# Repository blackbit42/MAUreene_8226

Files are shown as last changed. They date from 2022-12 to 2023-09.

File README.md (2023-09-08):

> [!WARNING]
> The current revision of the board is not functional. Build only if you want to work on fixing it.

# Token Ring MAU 'MAUreen'

MAUreene 8226 is a Token Ring (IEEE 802.5) Media Access Unit (MAU) that is inspired by the IBM 8226. For the most part, it is a reproduction of the IBM 8226, reduced to 2 'lobes', which is Token Ring lingo for what is known as a port in the context of other network technologies.

## Motivation

Token Ring is an interesting LAN technology. NICs are all over common auction sites and can be had cheaply, though MAUs are hard to come by. The intent of this project is to enable inclined people to play with Token Ring more easily.

## Clarification regarding 'crossover' cables

In an ethernet network you can nowadays connect two arbitrary devices with each other back to back without thinking about it, due to to the power of Auto MDI-X. Earlier you could use so-called 'crossover' cables. Unfortunately Token Ring doesn't support such a mode of interconnection, as a NIC goes through a mildly elaborated attachment process with a MAU. A mode where two hosts talk directly to each other doesn't exist, see [this](https://www.tavi.co.uk/ps2pages/ohland/8228.html#DirectCable).

## BOM analysis and mapping

| Original 8226 | Lobe 1 | Lobe 2  | Package | Type | Measured value[^1] | Marking | Remarks |
| --- | --- | --- | --- | --- | --- | --- | --- |
| R2 | R1 | R21 | 0805 | | 4.8k | 4871 | |
| R10 | R2 | R22 | 0603 | | -None- | -None- | Opto-coupler biasing, not populated |
| R34 | R3 | R23 | 0603 | | 0.3 | 000 | RJ45 termination |
| R35 | R4 | R24 | 0603 | | 0.3 | 000 | RJ45 termination |
| R44 | R5 | R25 | 0603 | | 100 | 101 | |
| R52 | R6 | R26 | 0603 | | 100 | 101 | |
| R60 | R7 | R27 | 0603 | | | 104 | |
| R68 | R8 | R28 | 0603 | | 10k | 103 | |
| R76 | R9 | R29 | 0603 | | 2k | 202 | |
| R84 | R10 | R30 | 0805 | | 3.7k | 3741 | |
| R92 | R11 | R31 | 0603 | | 4.7k | 472 | LED series resistor |
| R96 | R12 | R32 | 0603 | | 0.3 | 000 | RJ45 termination |
| R97 | R13 | R33 | 0603 | | 0.3 | 000 | RJ45 termination |
| C4 | C1 | C21 | 1812 | Ceramic | 330n | -None- | |
| C12 | C2 | C22 | 1812 | Ceramic | 330n | -None- | |
| C20 | C3 | C23 | EIA 7343-31  | Tantalum | 22u | 22-20 LD (2) | |
| C34 | C4 | C24 | 0805 | Ceramic | 120n | -None- | |
| C41 | C5 | C25 | 0805 | Ceramic | 120n | -None- | |
| Q13 | Q1 | Q21 | SOT23 | BJT NPN | | 1P | |
| Q14 | Q2 | Q22 | SOT23 | BJT NPN | | 1P | |
| CR7 | D1 | D21 | SOT23 | | 0.6 | A66 (?) | Flyback diode for coil in K2 |
| K2[^2] | K1 | K21 | Non-standard | 4PDT | | P&B T84S17D214-12 | |
| T2 | T1 | T21 | Non-standard | Special Token Ring | | Valor PT4043 | |
| DS2 | -None- | -None-  | Non-standard | | | -None- | LEDs of J1A and J1B are used |
| L2 | -None- | -None-  | -None- | -None- | | -None- | Unpopulated |
| U2 | U1 | U21 | DIP-6 | Opto-Coupler | | QTC H11A1 | | 
| -None- | J1A | J1B | Non-standard | RJ45 jack | | | |

## Power supply BOM

| Part designator | Value  | Description |
| --- | --- | --- |
| J200 | | Barrel jack |
| J201 | | 2x2 jumper 12V |
| J202 | | 2x2 jumper 5V  |
| U200 | | 5V linear reg. |
| C200 | 0.33uF | |
| C201 | 0.1uF  | |
| C202 | 0.1uF  | |
| R200 | 495Ohm | 12V rail ind.  |
| R201 | 145Ohm | 5V rail ind. |

[^1]: Capacitors have been desoldered for measurement with HP 4262A LCR meter.
[^2]: The polarity of the coil supply is reversed, both in the original and this design. Irrelevant, as the relay coils do not have series diodes.

## Diode direction
CR7 is in a 3-pin SOT23 package, containing only a single diode. It is connected in parallel with a relay coil, indicating reverse EMF protection for adjacent devices in the circuit.
Unfortunately somebody got the direction wrong, hence there is significant reverse EMF with spikes of around 200V. 
Remarkably, neither the diode itself dies from excessive forward current when the relay is on, nor the switching transistor from the voltage spikes when the relay is being switched off.
In the design of this contraption, a diode with normal flyback operation has been foreseen.

## Pictures

Photo:

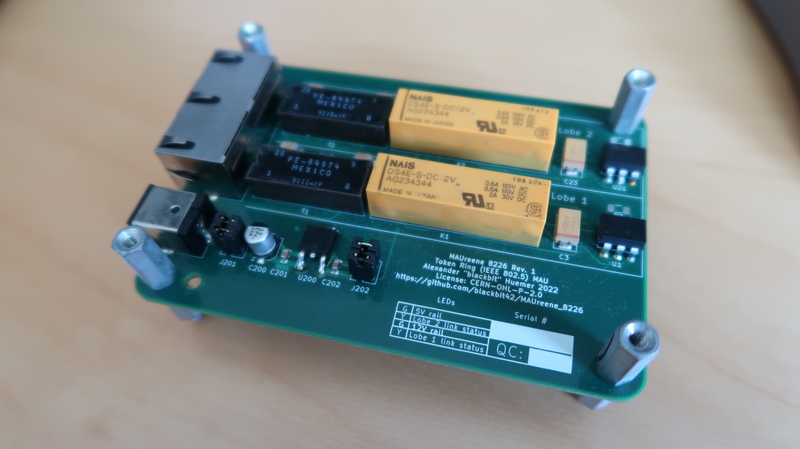
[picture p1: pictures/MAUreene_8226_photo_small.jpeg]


Kicad:

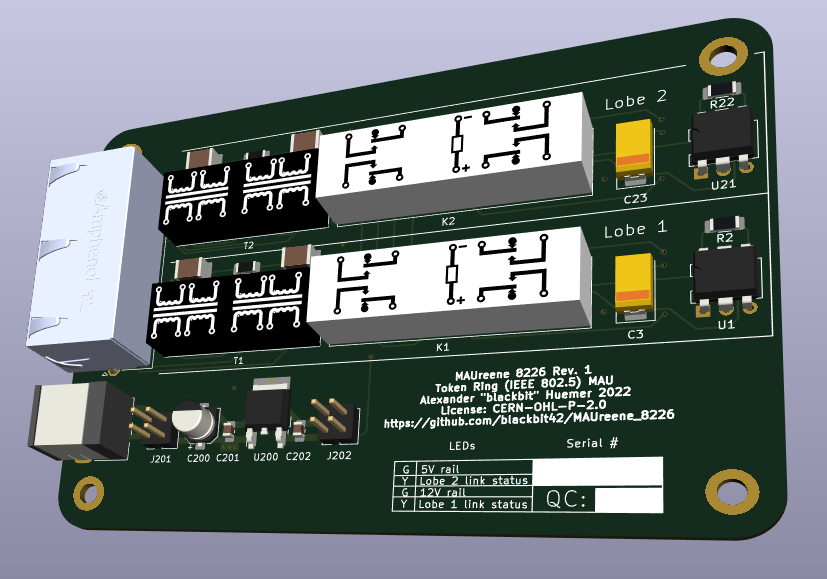
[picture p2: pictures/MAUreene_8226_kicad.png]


FreeCAD:

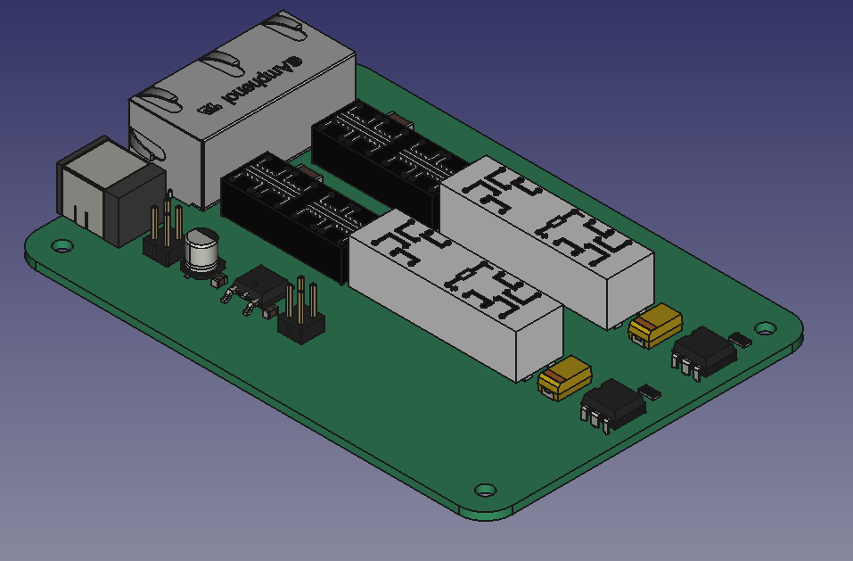
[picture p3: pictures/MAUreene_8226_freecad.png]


X-ray of original PCB, courtesy of [@Manawyrm](https://github.com/Manawyrm):

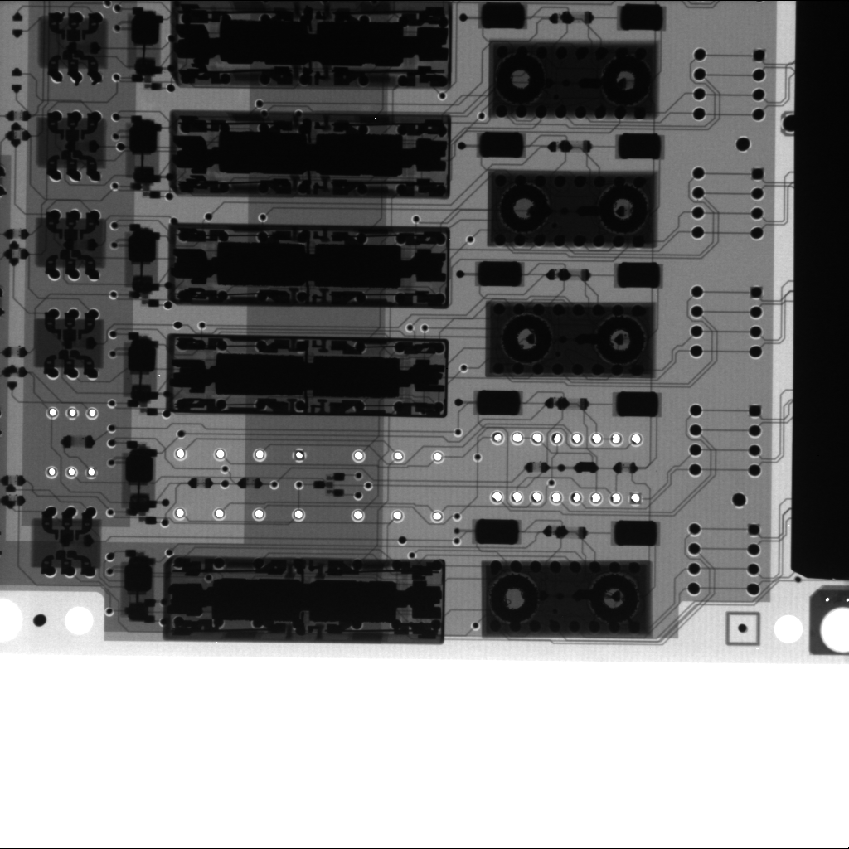
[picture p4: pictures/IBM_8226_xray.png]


## Links

<https://www.ieee802.org/5/www8025org/>

<https://ardent-tool.com/network/Understanding_Token_Ring.html>

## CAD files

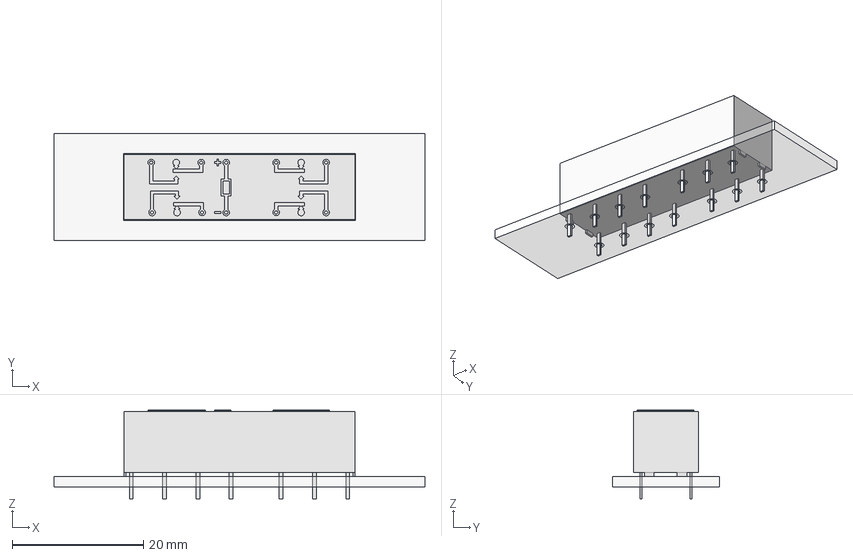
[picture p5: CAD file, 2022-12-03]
Freecad_models/4PDT_Relay.FCStd
56.6 x 16.3 x 13.5 mm
FrontSilk
TopPads
BotPads
PTHs
Pcb
4PDT_Relay

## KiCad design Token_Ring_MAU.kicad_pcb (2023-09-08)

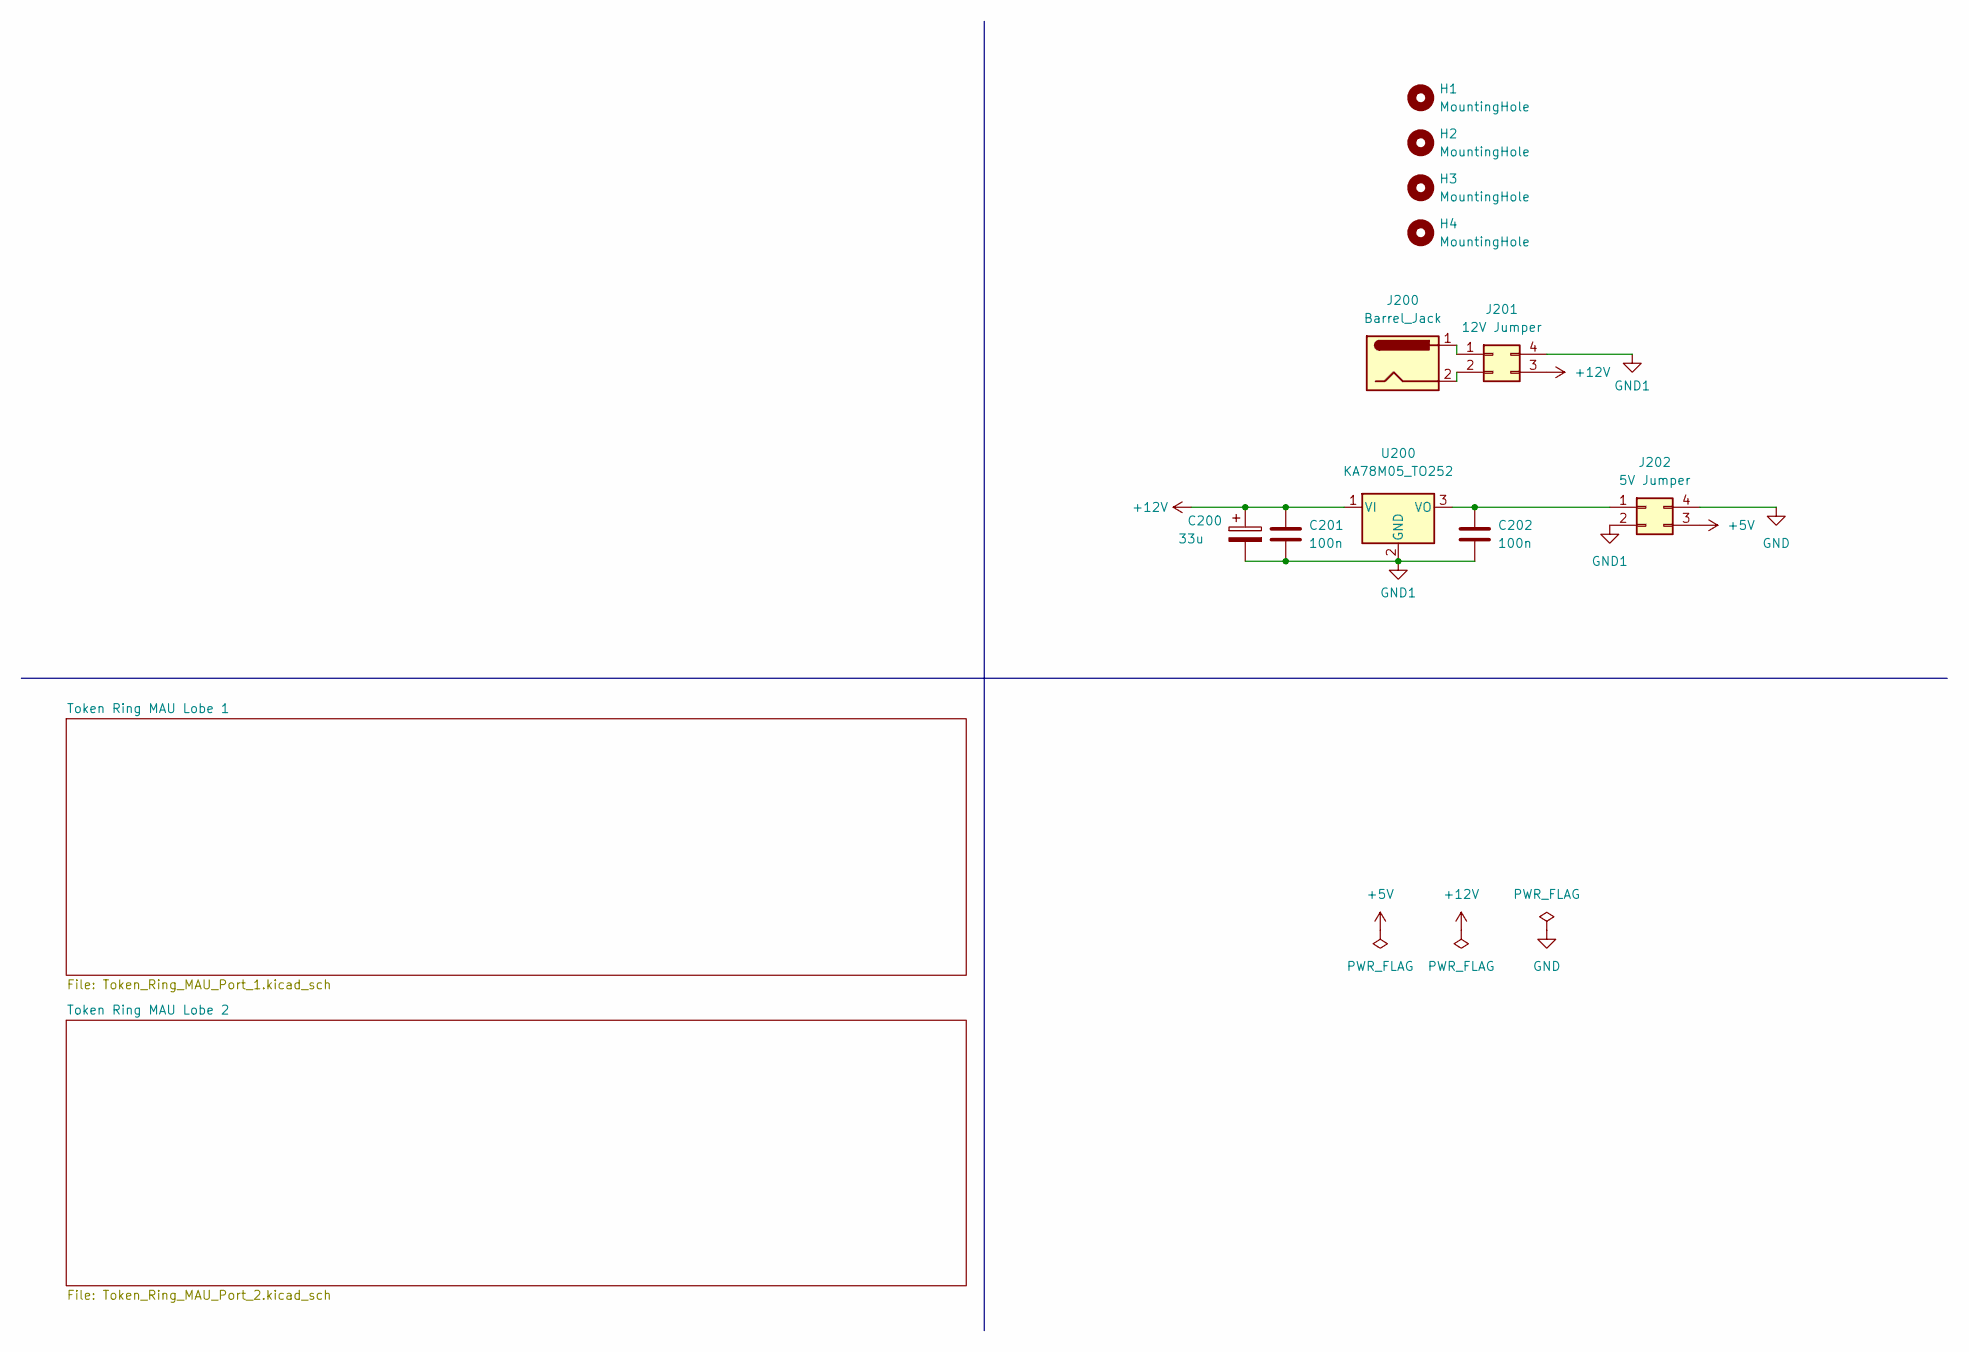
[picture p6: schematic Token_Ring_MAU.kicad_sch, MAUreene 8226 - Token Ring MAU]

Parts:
C200: 33u; CP_Elec_5x5.8; JLCPCB part number C128455
C201, C202: 100n; C_0805_2012Metric_Pad1.18x1.45mm_HandSolder; JLCPCB part number C85866
H1, H2, H3, H4: MountingHole; MountingHole_3.2mm_M3_DIN965_Pad; JLCPCB part number DNP
J200: Barrel_Jack; BarrelJack_CUI_PJ-063AH_Horizontal; JLCPCB part number DNP
J201: 12V Jumper; PinHeader_2x02_P2.54mm_Vertical; JLCPCB part number DNP
J202: 5V Jumper; PinHeader_2x02_P2.54mm_Vertical; JLCPCB part number DNP
U200: KA78M05_TO252; TO-252-2; JLCPCB part number DNP

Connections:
+5V: J202.3; also elsewhere on the board
+12V: C200.1, C201.1, J201.3, U200.1 (VI); also elsewhere on the board
GND: J202.4; also elsewhere on the board
GND1: C200.2, C201.2, C202.2, J201.4, J202.2, U200.2 (GND)
unnamed: C202.1, J202.1, U200.3 (VO)
unnamed: J200.1, J201.1
unnamed: J200.2, J201.2

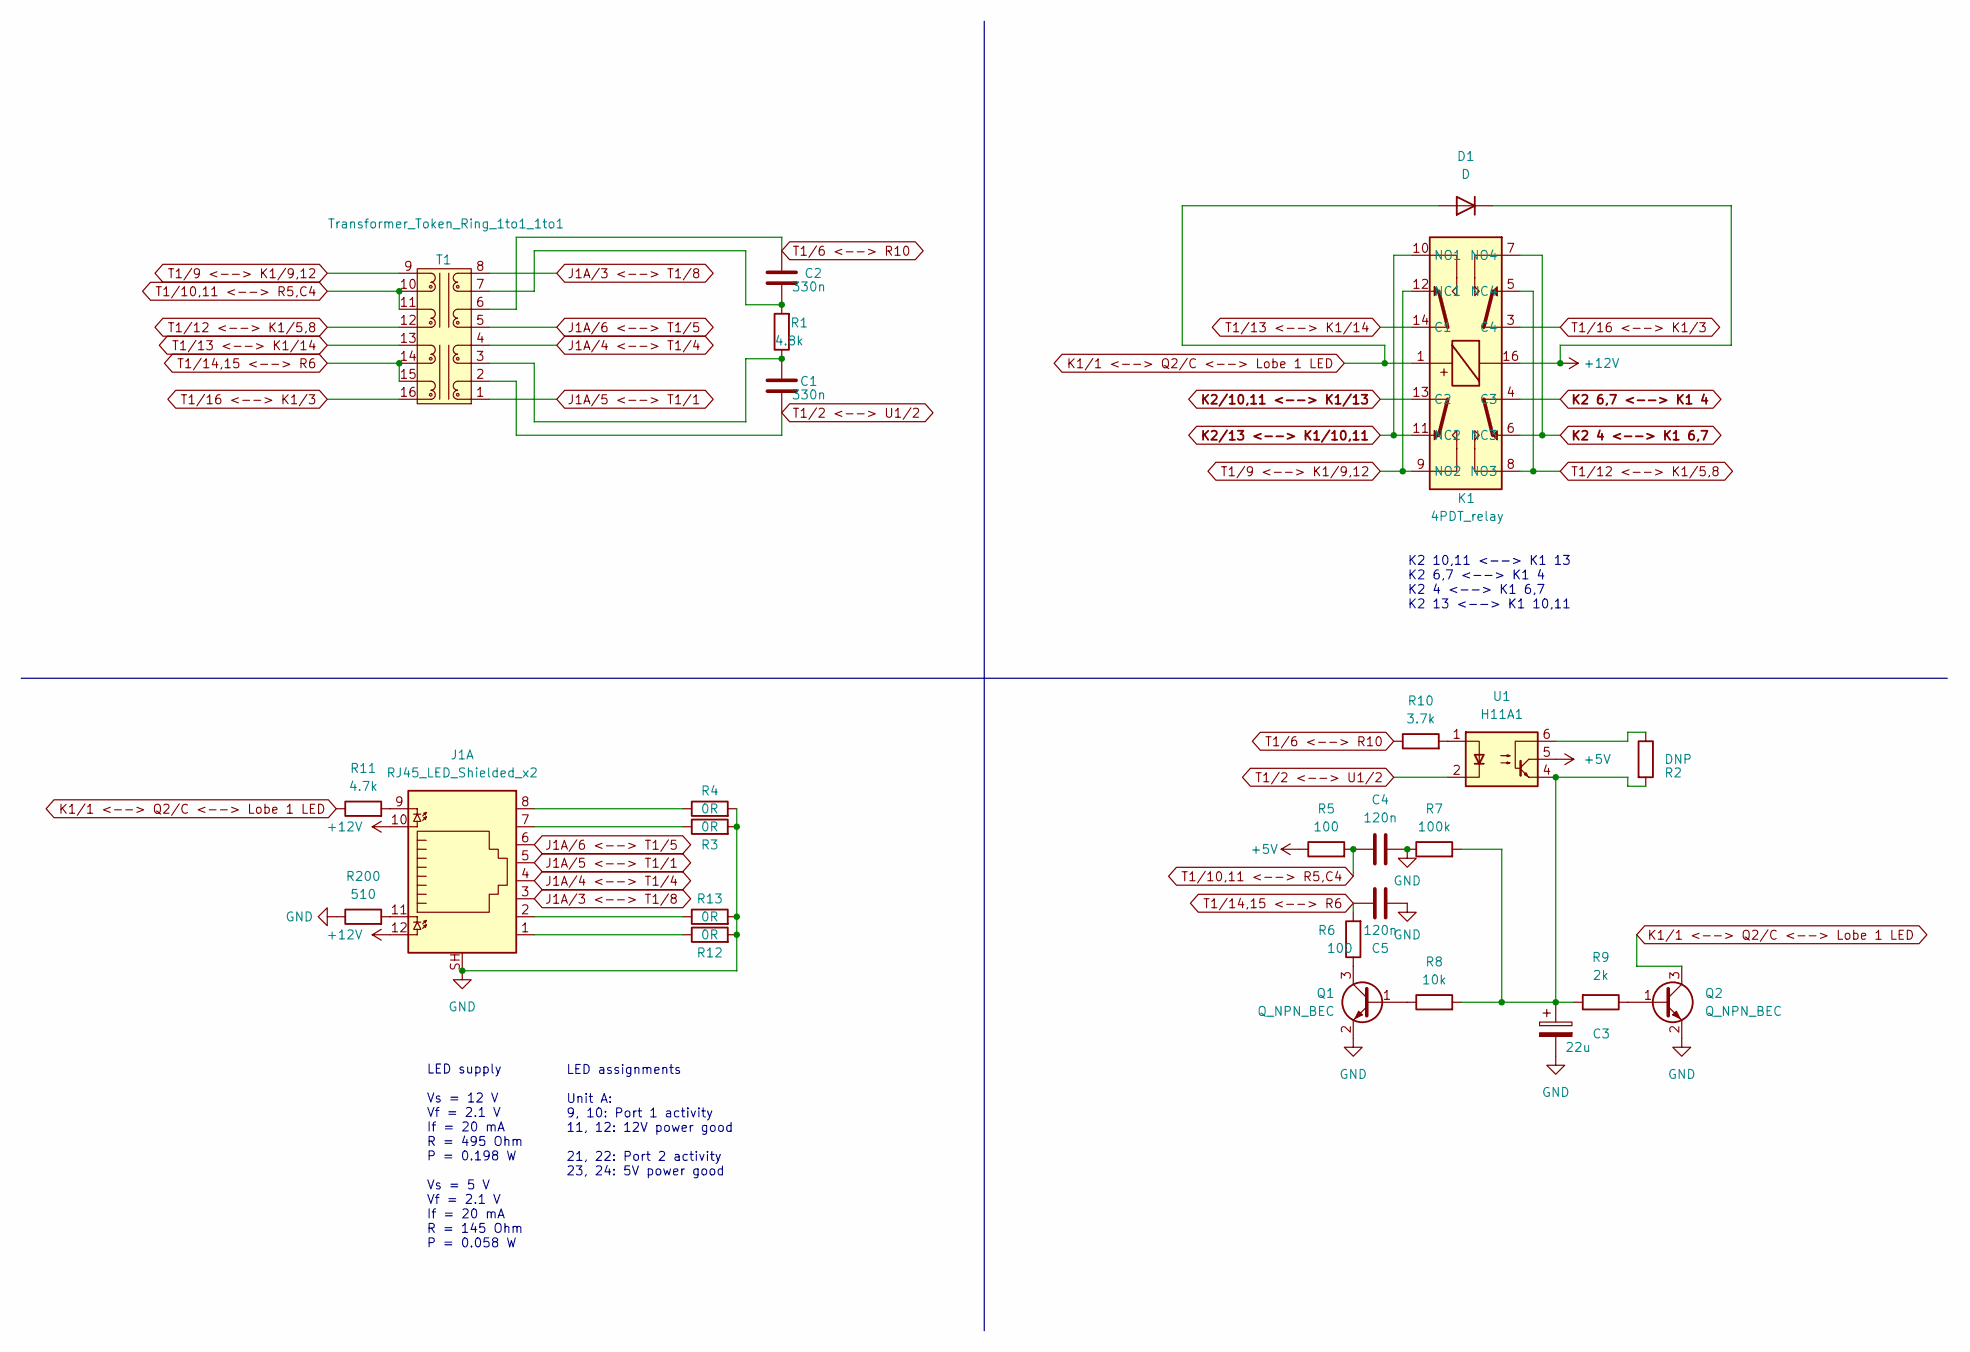
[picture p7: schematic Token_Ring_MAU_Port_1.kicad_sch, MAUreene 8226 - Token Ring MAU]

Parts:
C1, C2: 330n; C_1812_4532Metric_Pad1.57x3.40mm_HandSolder; JLCPCB part number C106167
C3: 22u; CP_EIA-7343-31_Kemet-D_Pad2.25x2.55mm_HandSolder; JLCPCB part number C7225
C4, C5: 120n; C_0603_1608Metric_Pad1.08x0.95mm_HandSolder; JLCPCB part number C282672
D1: D; D_SOD-123F; JLCPCB part number C108803
J1: RJ45_LED_Shielded_x2; RJ45_Amphenol_RJHSE538X-02; JLCPCB part number DNP
K1: 4PDT_relay; 4PDT_Relay; JLCPCB part number DNP
Q1, Q2: Q_NPN_BEC; SOT-23; JLCPCB part number C141788
R1: 4.8k; R_1206_3216Metric_Pad1.30x1.75mm_HandSolder; JLCPCB part number C323071
R2: DNP; R_1206_3216Metric_Pad1.30x1.75mm_HandSolder; JLCPCB part number DNP
R3, R4, R12, R13: 0R; R_0603_1608Metric_Pad0.98x0.95mm_HandSolder; JLCPCB part number C21189
R5, R6: 100; R_0603_1608Metric_Pad0.98x0.95mm_HandSolder; JLCPCB part number C445624
R7: 100k; R_0603_1608Metric_Pad0.98x0.95mm_HandSolder; JLCPCB part number C150003
R8: 10k; R_0603_1608Metric_Pad0.98x0.95mm_HandSolder; JLCPCB part number C100708
R9: 2k; R_0603_1608Metric_Pad0.98x0.95mm_HandSolder; JLCPCB part number C217936
R10: 3.7k; R_0805_2012Metric_Pad1.20x1.40mm_HandSolder; JLCPCB part number C403190
R11: 4.7k; R_0603_1608Metric_Pad0.98x0.95mm_HandSolder; JLCPCB part number C105428
R200: 510; R_0603_1608Metric_Pad0.98x0.95mm_HandSolder; JLCPCB part number C23193
T1: Transformer_Token_Ring_1to1_1to1; Pulse PE-64974; JLCPCB part number DNP
U1: H11A1; DIP-6_W7.62mm; JLCPCB part number DNP

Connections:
+5V: R5.1, U1.5; also elsewhere on the board
+12V: D1.1 (K), J1.10, J1.12, K1.16; also elsewhere on the board
GND: C3.2, C4.2, C5.2, J1.SH, Q1.2 (E), Q2.2 (E), R3.2, R4.2, R7.1, R12.2, R13.2, R200.1; also elsewhere on the board
J1A/3 <--> T1/8: J1.3, T1.8
J1A/4 <--> T1/4: J1.4, T1.4
J1A/5 <--> T1/1: J1.5, T1.1
J1A/6 <--> T1/5: J1.6, T1.5
K1/1 <--> Q2/C <--> Lobe 1 LED: D1.2 (A), K1.1, Q2.3 (C), R11.1
K2 4 <--> K1 6,7: K1.6 (NC3), K1.7 (NO4); also elsewhere on the board
K2 6,7 <--> K1 4: K1.4 (C3); also elsewhere on the board
K2/10,11 <--> K1/13: K1.13 (C2); also elsewhere on the board
K2/13 <--> K1/10,11: K1.10 (NO1), K1.11 (NC2); also elsewhere on the board
unnamed: C1.1, R1.1, T1.3
unnamed: C2.2, R1.2, T1.7
unnamed: C3.1, R2.2, R7.2, R8.2, R9.2, U1.4
unnamed: J1.1, R12.1
unnamed: J1.2, R13.1
unnamed: J1.7, R3.1
unnamed: J1.8, R4.1
unnamed: J1.9, R11.2
unnamed: J1.11, R200.2
unnamed: Q1.1 (B), R8.1
unnamed: Q1.3 (C), R6.1
unnamed: Q2.1 (B), R9.1
unnamed: R2.1, U1.6
unnamed: R10.2, U1.1
T1/2 <--> U1/2: C1.2, T1.2, U1.2
T1/6 <--> R10: C2.1, R10.1, T1.6
T1/9 <--> K1/9,12: K1.9 (NO2), K1.12 (NC1), T1.9
T1/10,11 <--> R5,C4: C4.1, R5.2, T1.10, T1.11
T1/12 <--> K1/5,8: K1.5 (NC4), K1.8 (NO3), T1.12
T1/13 <--> K1/14: K1.14 (C1), T1.13
T1/14,15 <--> R6: C5.1, R6.2, T1.14, T1.15
T1/16 <--> K1/3: K1.3 (C4), T1.16

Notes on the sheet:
K2 10,11 <--> K1 13 K2 6,7 <--> K1 4 K2 4 <--> K1 6,7 K2 13 <--> K1 10,11
LED assignments Unit A: 9, 10: Port 1 activity 11, 12: 12V power good 21, 22: Port 2 activity 23, 24: 5V power good
LED supply Vs = 12 V Vf = 2.1 V If = 20 mA R = 495 Ohm P = 0.198 W Vs = 5 V Vf = 2.1 V If = 20 mA R = 145 Ohm P = 0.058 W

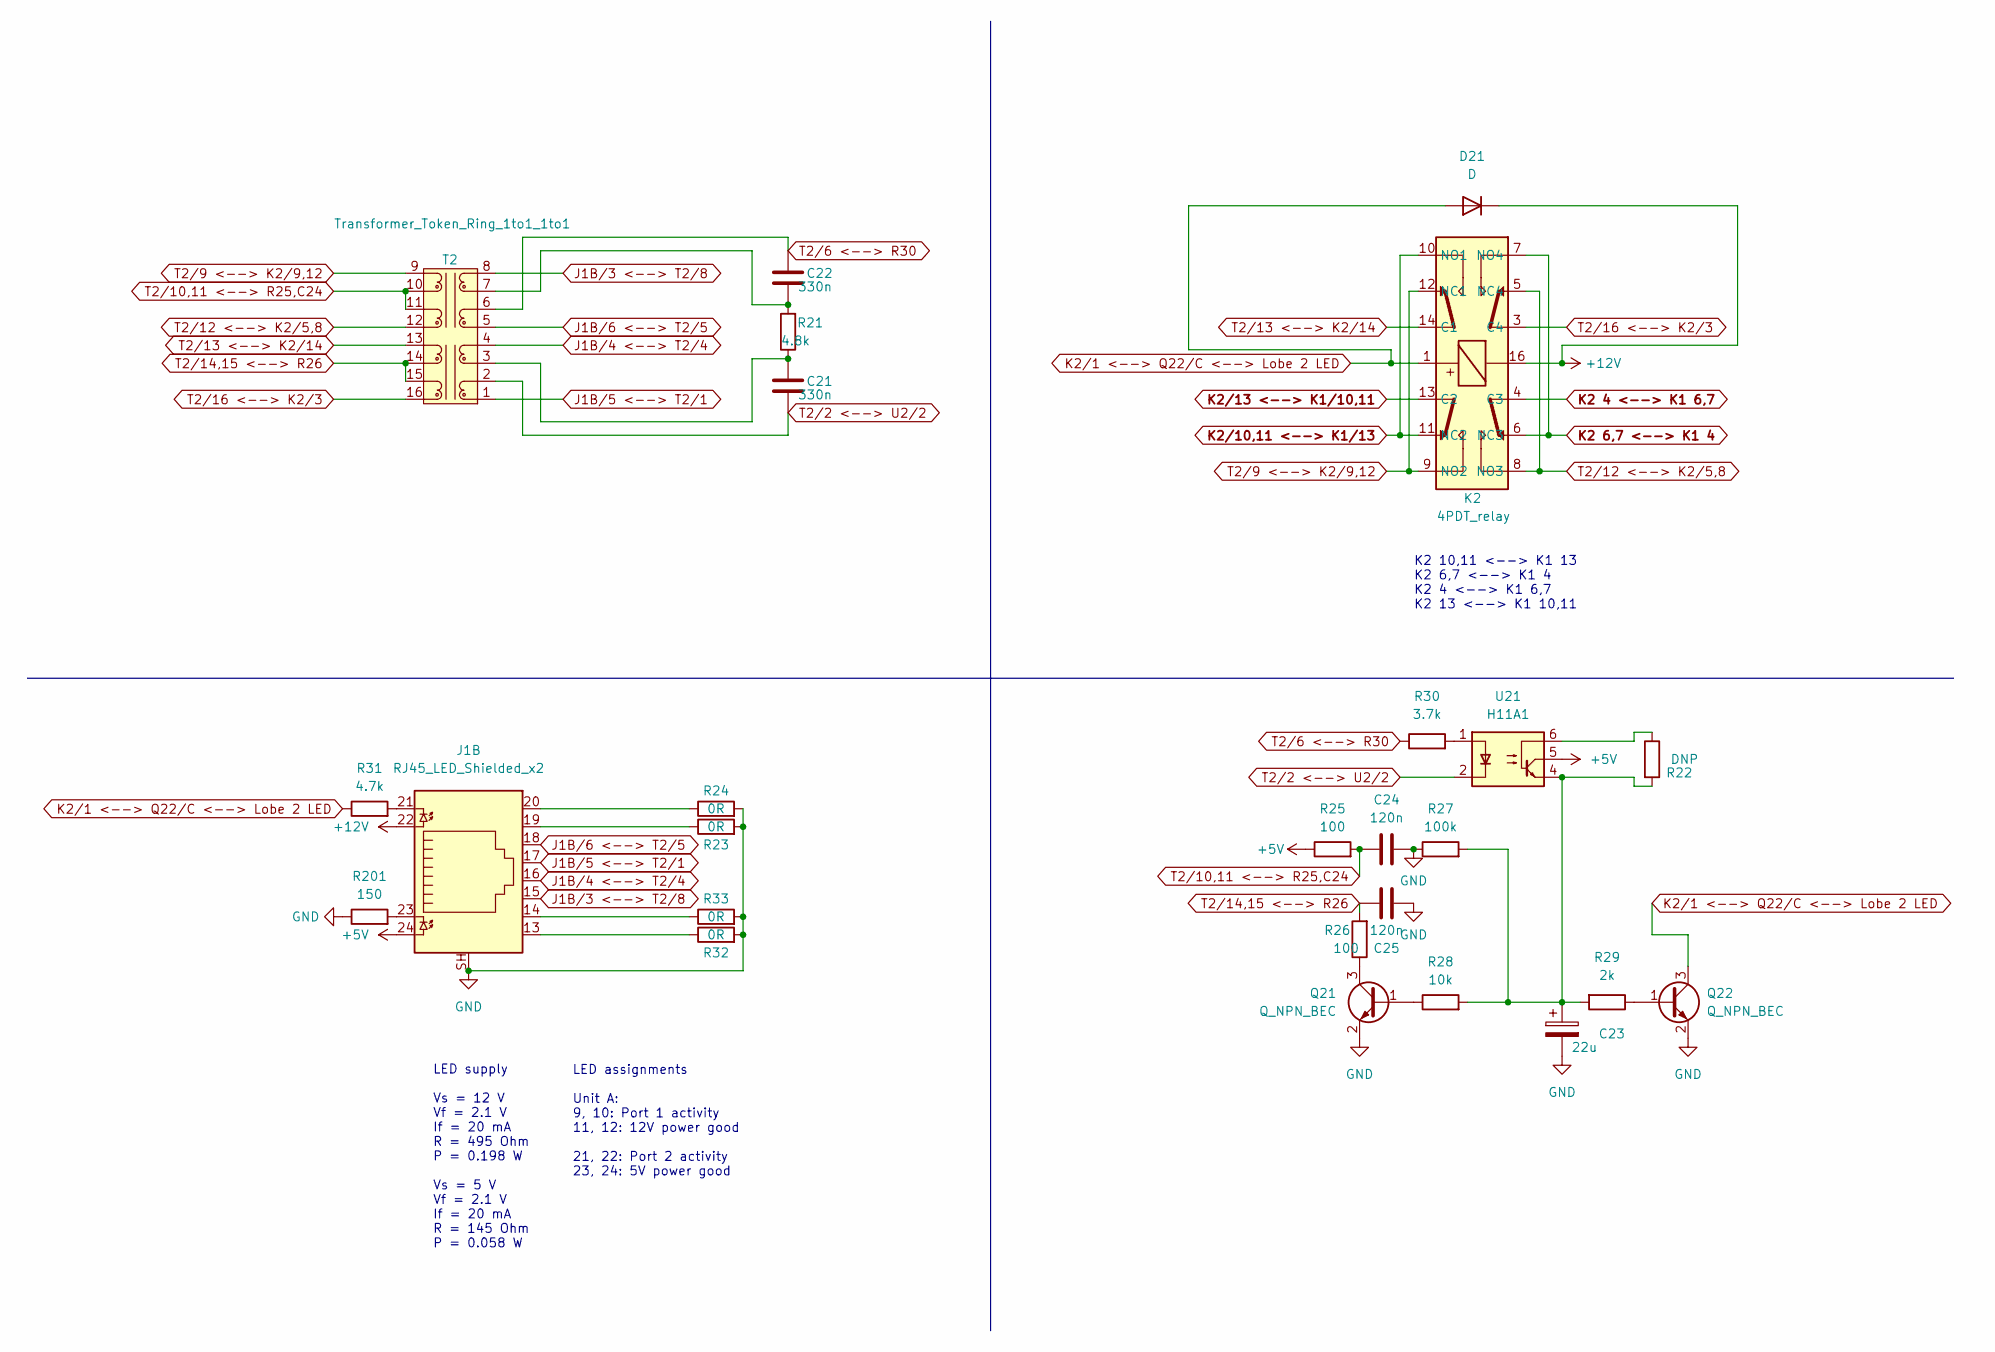
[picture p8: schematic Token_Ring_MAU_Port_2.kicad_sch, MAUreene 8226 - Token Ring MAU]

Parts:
C21, C22: 330n; C_1812_4532Metric_Pad1.57x3.40mm_HandSolder; JLCPCB part number C106167
C23: 22u; CP_EIA-7343-31_Kemet-D_Pad2.25x2.55mm_HandSolder; JLCPCB part number C7225
C24, C25: 120n; C_0603_1608Metric_Pad1.08x0.95mm_HandSolder; JLCPCB part number C282672
D21: D; D_SOD-123F; JLCPCB part number C108803
J1: RJ45_LED_Shielded_x2; RJ45_Amphenol_RJHSE538X-02; JLCPCB part number DNP
K2: 4PDT_relay; 4PDT_Relay; JLCPCB part number DNP
Q21, Q22: Q_NPN_BEC; SOT-23; JLCPCB part number C141788
R21: 4.8k; R_1206_3216Metric_Pad1.30x1.75mm_HandSolder; JLCPCB part number C323071
R22: DNP; R_1206_3216Metric_Pad1.30x1.75mm_HandSolder; JLCPCB part number DNP
R23, R24, R32, R33: 0R; R_0603_1608Metric_Pad0.98x0.95mm_HandSolder; JLCPCB part number C21189
R25, R26: 100; R_0603_1608Metric_Pad0.98x0.95mm_HandSolder; JLCPCB part number C445624
R27: 100k; R_0603_1608Metric_Pad0.98x0.95mm_HandSolder; JLCPCB part number C150003
R28: 10k; R_0603_1608Metric_Pad0.98x0.95mm_HandSolder; JLCPCB part number C100708
R29: 2k; R_0603_1608Metric_Pad0.98x0.95mm_HandSolder; JLCPCB part number C217936
R30: 3.7k; R_0805_2012Metric_Pad1.20x1.40mm_HandSolder; JLCPCB part number C403190
R31: 4.7k; R_0603_1608Metric_Pad0.98x0.95mm_HandSolder; JLCPCB part number C105428
R201: 150; R_0603_1608Metric_Pad0.98x0.95mm_HandSolder; JLCPCB part number C227596
T2: Transformer_Token_Ring_1to1_1to1; Pulse PE-64974; JLCPCB part number DNP
U21: H11A1; DIP-6_W7.62mm; JLCPCB part number DNP

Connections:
+5V: J1.24, R25.1, U21.5; also elsewhere on the board
+12V: D21.1 (K), J1.22, K2.16; also elsewhere on the board
GND: C23.2, C24.2, C25.2, J1.SH, Q21.2 (E), Q22.2 (E), R23.2, R24.2, R27.1, R32.2, R33.2, R201.1; also elsewhere on the board
J1B/3 <--> T2/8: J1.15, T2.8
J1B/4 <--> T2/4: J1.16, T2.4
J1B/5 <--> T2/1: J1.17, T2.1
J1B/6 <--> T2/5: J1.18, T2.5
K2 4 <--> K1 6,7: K2.4 (C3); also elsewhere on the board
K2 6,7 <--> K1 4: K2.6 (NC3), K2.7 (NO4); also elsewhere on the board
K2/1 <--> Q22/C <--> Lobe 2 LED: D21.2 (A), K2.1, Q22.3 (C), R31.1
K2/10,11 <--> K1/13: K2.10 (NO1), K2.11 (NC2); also elsewhere on the board
K2/13 <--> K1/10,11: K2.13 (C2); also elsewhere on the board
unnamed: C21.1, R21.1, T2.3
unnamed: C22.2, R21.2, T2.7
unnamed: C23.1, R22.2, R27.2, R28.2, R29.2, U21.4
unnamed: J1.13, R32.1
unnamed: J1.14, R33.1
unnamed: J1.19, R23.1
unnamed: J1.20, R24.1
unnamed: J1.21, R31.2
unnamed: J1.23, R201.2
unnamed: Q21.1 (B), R28.1
unnamed: Q21.3 (C), R26.1
unnamed: Q22.1 (B), R29.1
unnamed: R22.1, U21.6
unnamed: R30.2, U21.1
T2/2 <--> U2/2: C21.2, T2.2, U21.2
T2/6 <--> R30: C22.1, R30.1, T2.6
T2/9 <--> K2/9,12: K2.9 (NO2), K2.12 (NC1), T2.9
T2/10,11 <--> R25,C24: C24.1, R25.2, T2.10, T2.11
T2/12 <--> K2/5,8: K2.5 (NC4), K2.8 (NO3), T2.12
T2/13 <--> K2/14: K2.14 (C1), T2.13
T2/14,15 <--> R26: C25.1, R26.2, T2.14, T2.15
T2/16 <--> K2/3: K2.3 (C4), T2.16

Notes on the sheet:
LED supply Vs = 12 V Vf = 2.1 V If = 20 mA R = 495 Ohm P = 0.198 W Vs = 5 V Vf = 2.1 V If = 20 mA R = 145 Ohm P = 0.058 W
LED assignments Unit A: 9, 10: Port 1 activity 11, 12: 12V power good 21, 22: Port 2 activity 23, 24: 5V power good
K2 10,11 <--> K1 13 K2 6,7 <--> K1 4 K2 4 <--> K1 6,7 K2 13 <--> K1 10,11

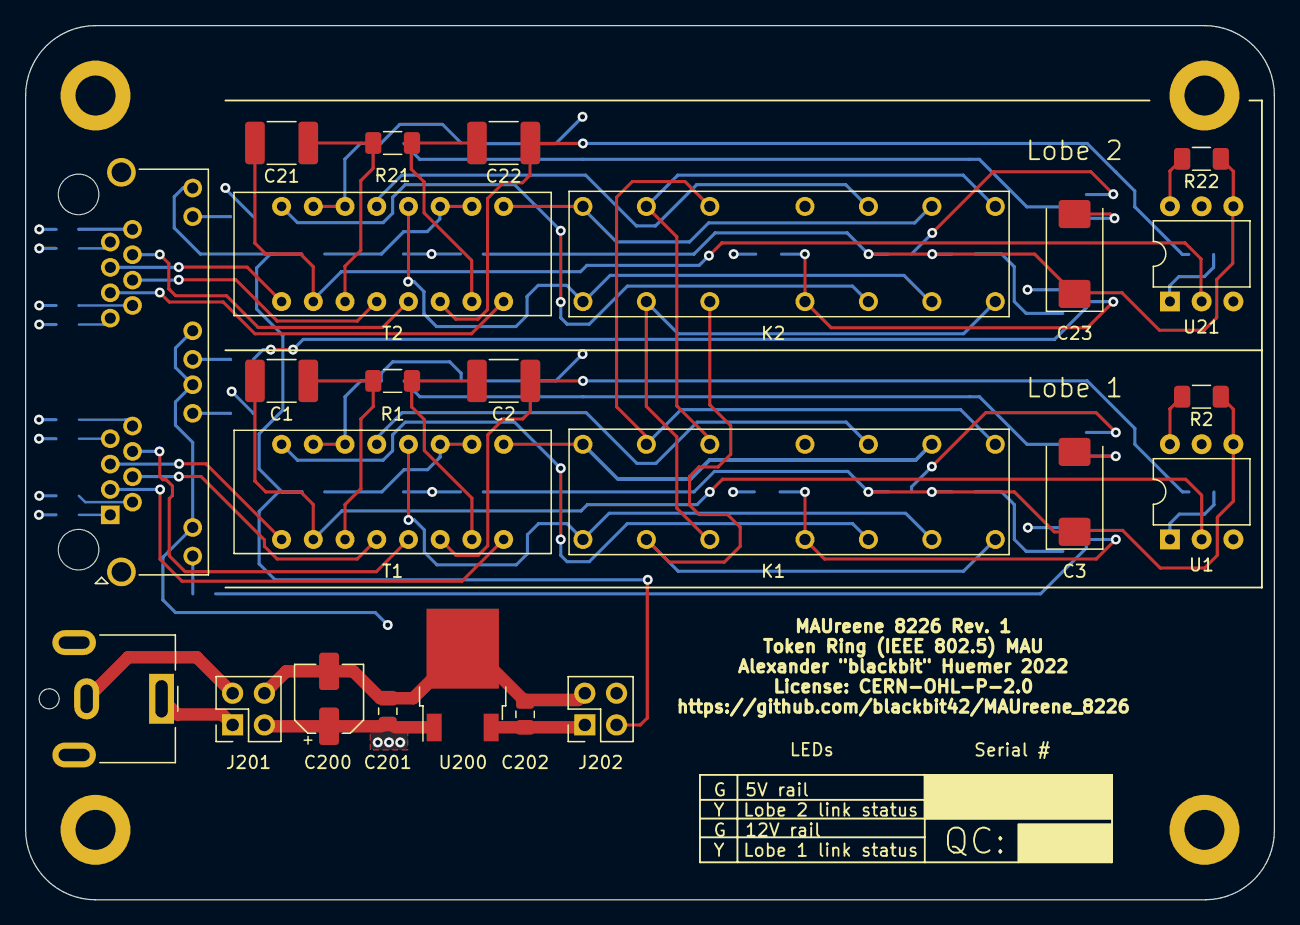
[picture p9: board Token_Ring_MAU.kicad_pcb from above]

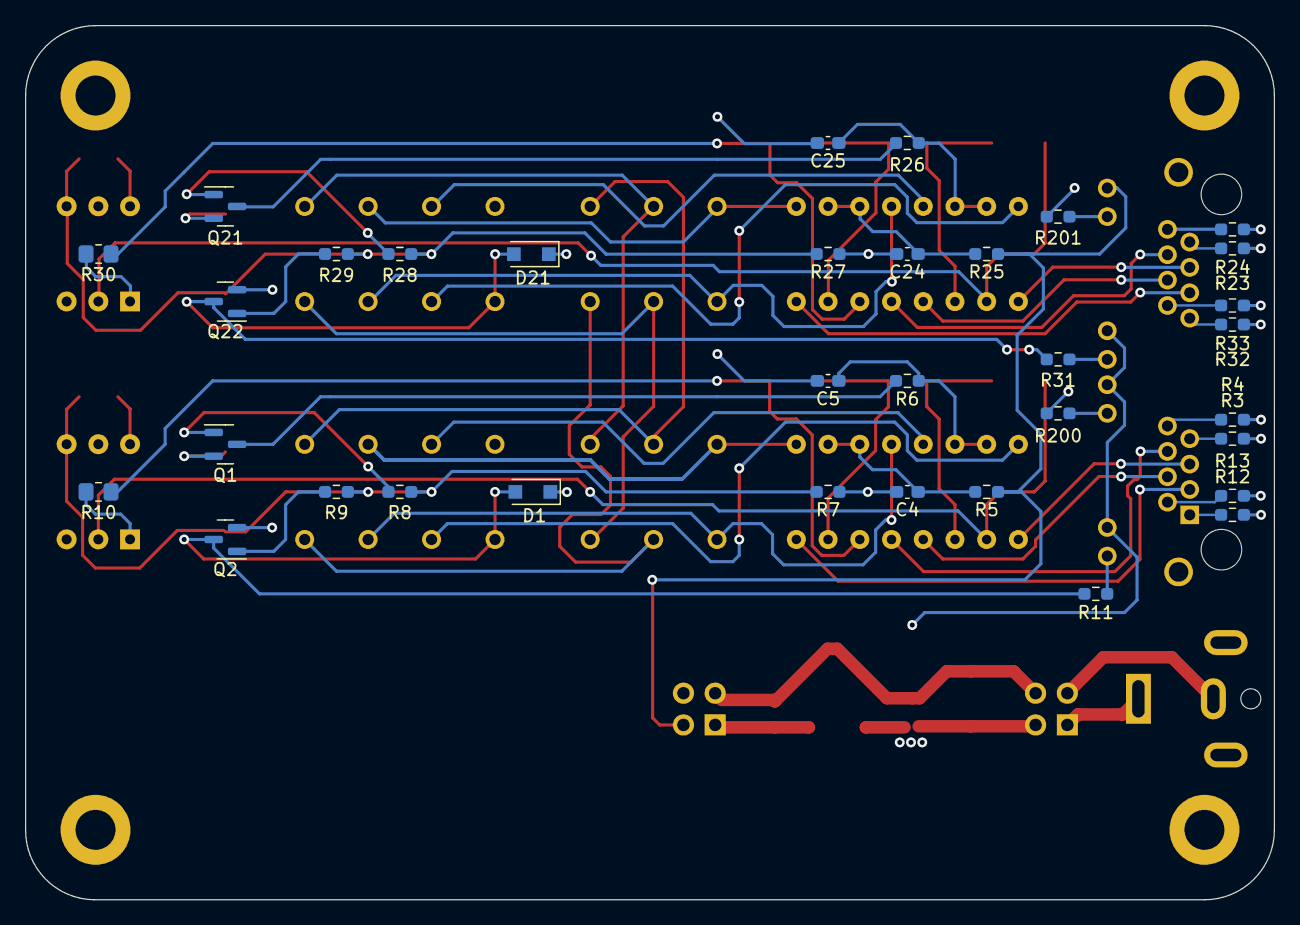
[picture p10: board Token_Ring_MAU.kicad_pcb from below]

Board: 4 copper layers, 100.0 x 70.0 mm, 62 parts (34 on the bottom side), 65 nets.

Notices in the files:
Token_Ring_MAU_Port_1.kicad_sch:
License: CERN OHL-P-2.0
